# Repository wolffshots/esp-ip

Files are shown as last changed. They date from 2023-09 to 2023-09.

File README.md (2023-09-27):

# ESP32 WiFi Network Interface Bridge

This project is a hardware solution that leverages the power of the ESP32 to bridge local communication interfaces, such as serial and (in the future) I2C, to a WiFi network. It allows devices with traditional communication interfaces to be accessed and controlled over WiFi.

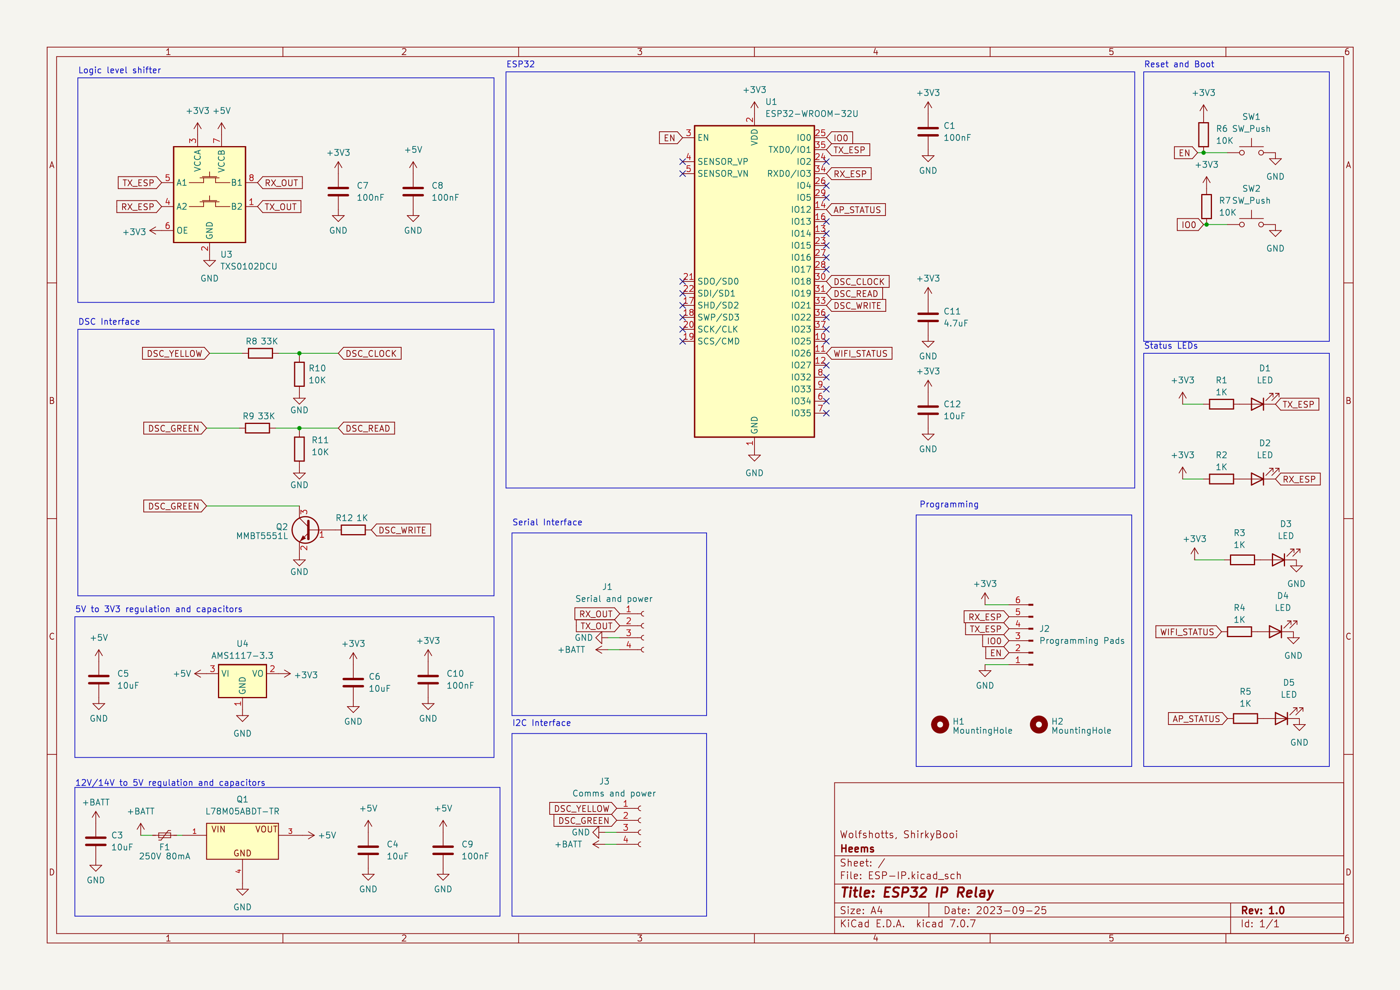
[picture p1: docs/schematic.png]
Schematic diagram


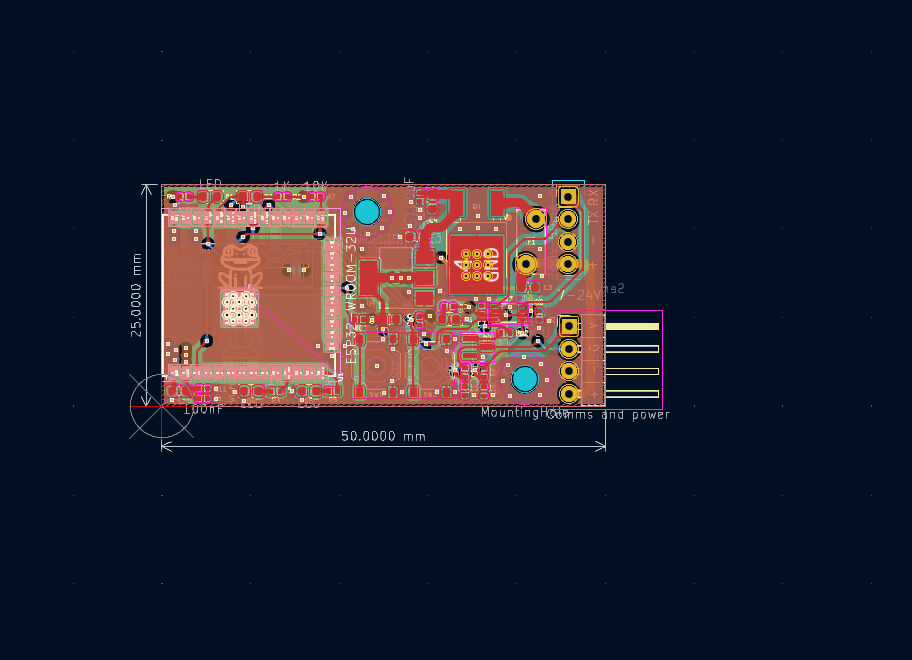
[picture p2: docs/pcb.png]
PCB diagram


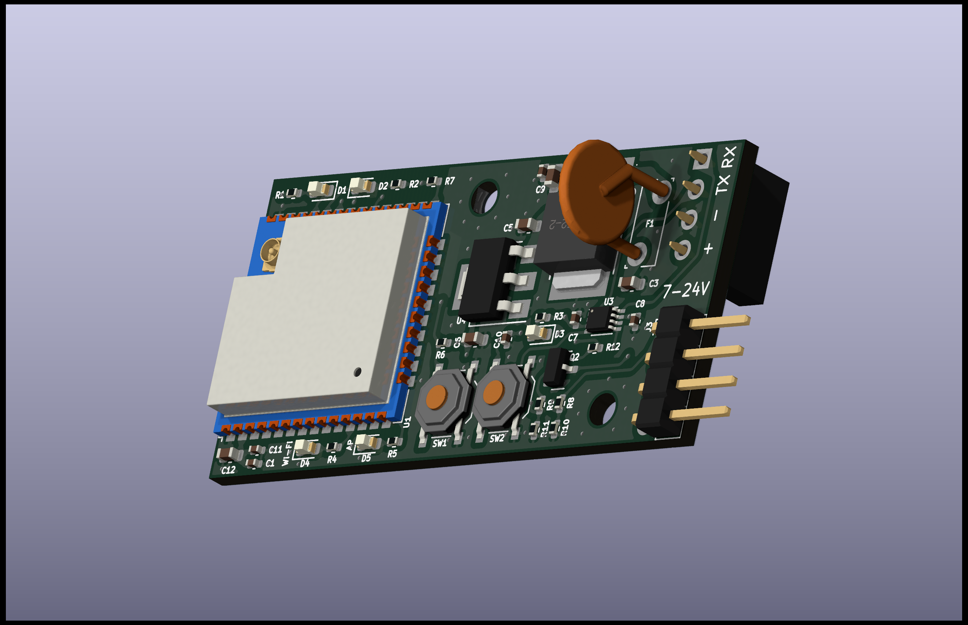
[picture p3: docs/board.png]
Board diagram


## Features

- **Interface Bridging**: Convert and expose devices using:
  - Serial interface (current implementation)
  - I2C interface (planned for future releases)
  
- **WiFi Connectivity**:
  - Connect to an existing WiFi network.
  - Broadcast its own Access Point (AP) for direct connections.

- **Status Indicators**:
  - **Serial Communication**:
    - RX LED: Lights up when the device receives data.
    - TX LED: Lights up when the device transmits data.
  - **WiFi Indicators**:
    - Connection LED: Lights up when the device is connected to an external WiFi.
    - AP LED: Lights up when the device is broadcasting its own Access Point.

## Hardware Design

- Designed in KiCad.
- ESP32-WROOM-32U as the main microcontroller.

## Getting Started

### Prerequisites

- KiCad for viewing and editing the design files.
- A compatible power source for the board.

### Setup

1. **Power the board**: Connect the board to a suitable power source.
2. **Connection**:
    - For Serial: Connect your serial device to the designated serial port.
    - For I2C (Future): Connect your I2C device to the designated I2C connectors.
3. **WiFi**:
    - Connect to an existing WiFi: Set the credentials in the firmware and upload to the ESP32.
    - Use as AP: The board will automatically broadcast its AP if it fails to connect to the saved networks.

### Configuration

Details about how users can configure the firmware for specific WiFi networks, adjust baud rates for serial communication, or other configuration details.

## Future Enhancements

- Integration of the I2C interface.
- Firmware updates over the air.

## Contribute

We welcome contributions! Please read the [CONTRIBUTING.md](./CONTRIBUTING.md) for details on submitting pull requests to us.

## License

This project is licensed under the XYZ License - see the [LICENSE.md](./LICENSE.md) file for details.

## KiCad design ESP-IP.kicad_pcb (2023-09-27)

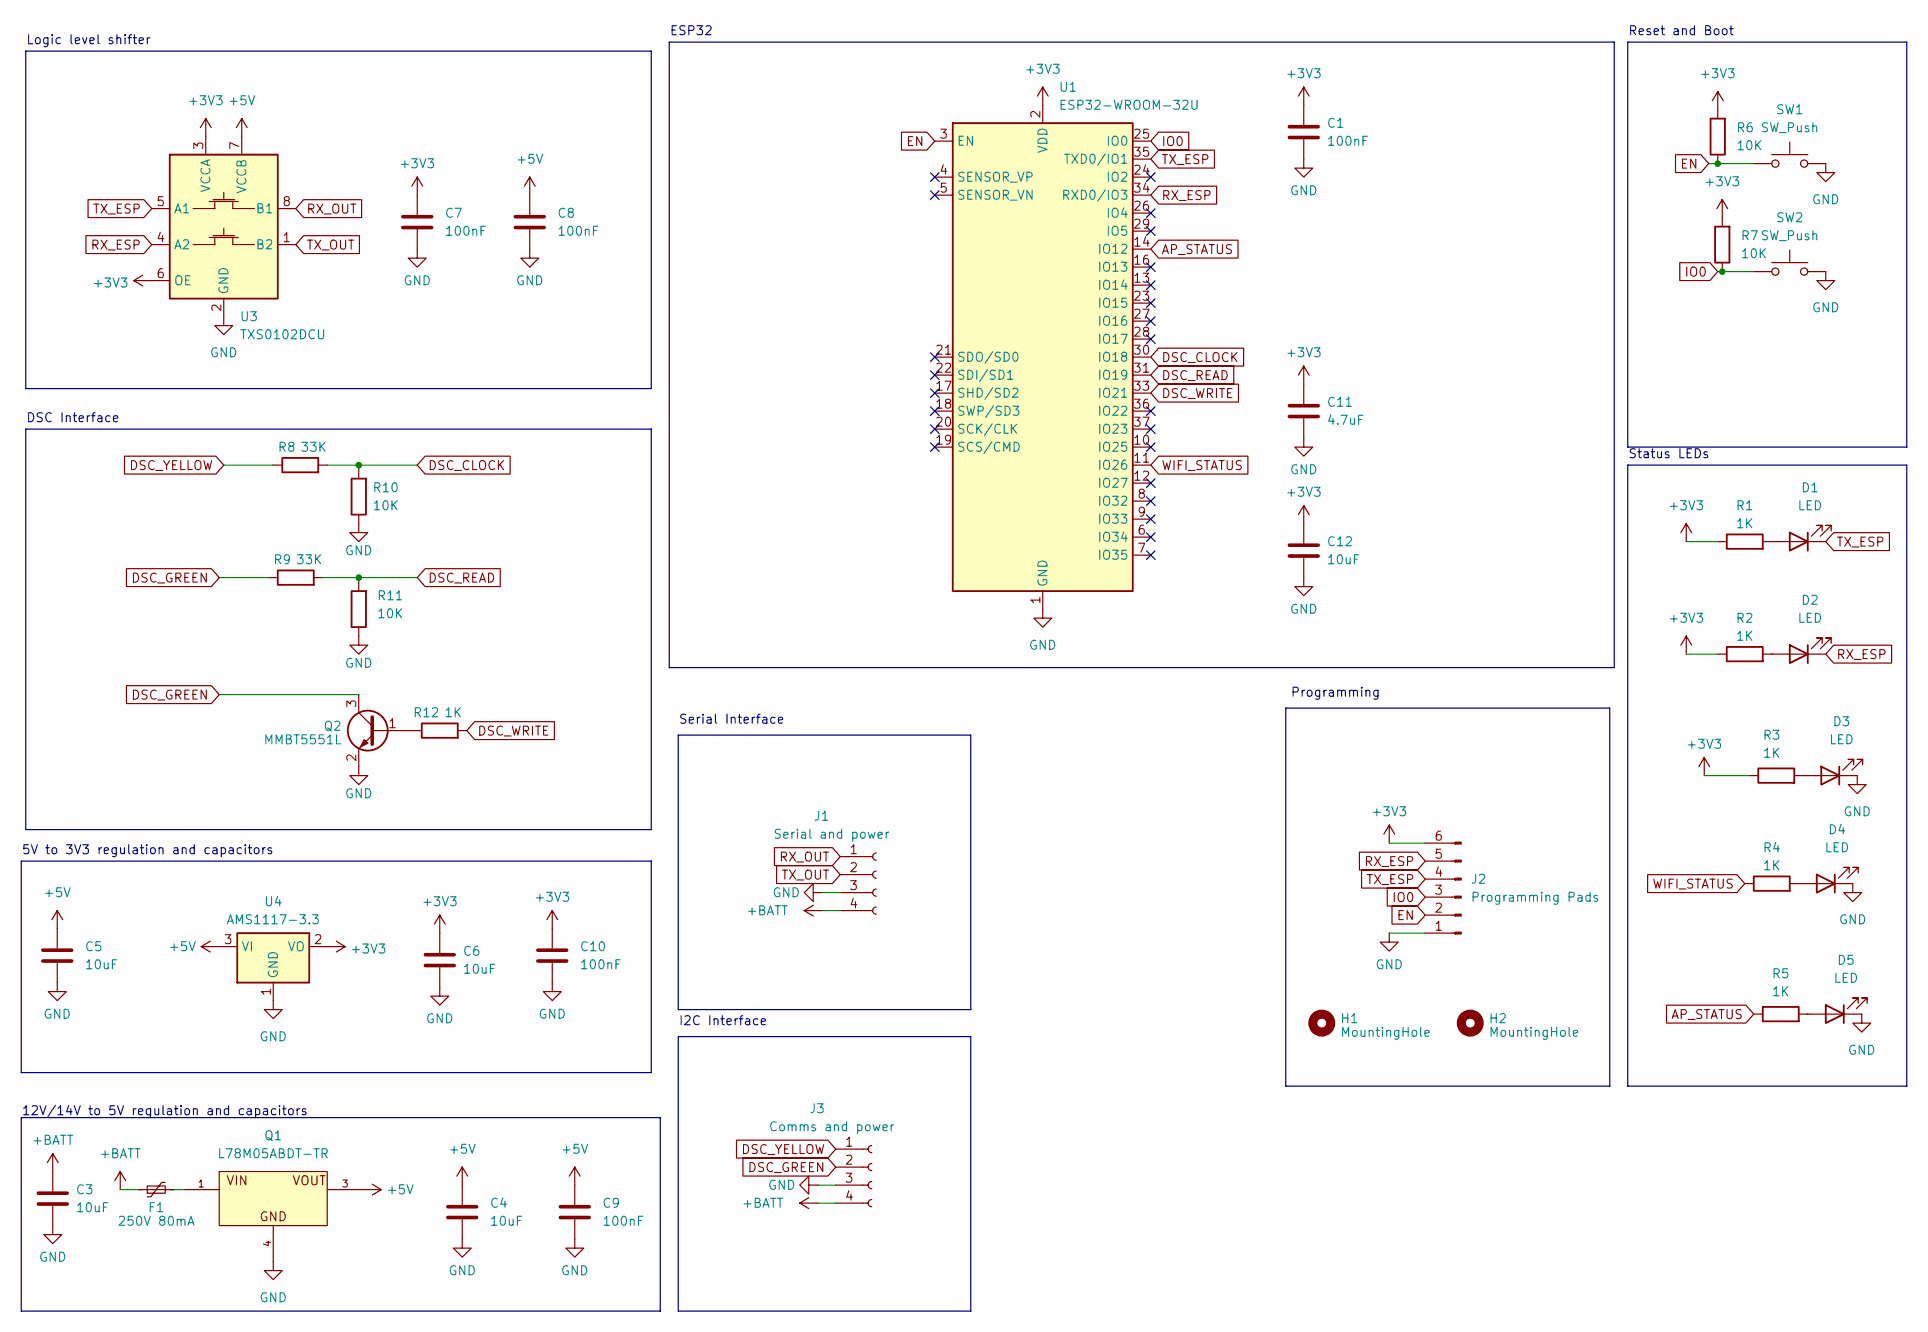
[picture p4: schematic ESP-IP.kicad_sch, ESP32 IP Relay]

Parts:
C1, C7, C8, C9, C10: 100nF; C_0402_1005Metric; LCSC C307331
C3, C4, C5, C6, C12: 10uF; C_0603_1608Metric; LCSC C57112
C11: 4.7uF; C_0402_1005Metric; LCSC C1538
D1, D2: LED; LED_0603_1608Metric; LCSC C2286
D3: LED; LED_0603_1608Metric; LCSC C72038
D4: LED; LED_0603_1608Metric; LCSC C72041
D5: LED; LED_0603_1608Metric; LCSC C72043
F1: 250V 80mA; Fuse_Bourns_MF-RG300; LCSC DNP
H1, H2: MountingHole; MountingHole_2.7mm_M2.5
J1: Serial and power; PinSocket_1x04_P2.54mm_Vertical; LCSC DNP
J2: Programming Pads; PinHeader_1x06_P2.54mm_Vertical_SMD_Pin1Left; LCSC DNP
J3: Comms and power; PinHeader_1x04_P2.54mm_Horizontal; LCSC DNP
Q1: L78M05ABDT-TR; TO-252-2_L6.5-W6.1-P4.58-LS10.0-TL; LCSC C58069
Q2: MMBT5551L; SOT-23; LCSC C2145
R1, R2, R3, R4, R5, R12: 1K; R_0402_1005Metric; LCSC C11702
R6, R7, R10, R11: 10K; R_0402_1005Metric; LCSC C25744
R8, R9: 33K; R_0402_1005Metric; LCSC C25779
SW1, SW2: SW_Push; SW_Push_1P1T_XKB_TS-1187A; LCSC C318884
U1: ESP32-WROOM-32U; ESP32-WROOM-32UE; LCSC DNP
U3: TXS0102DCU; VSSOP-8_2.3x2mm_P0.5mm; LCSC C53434
U4: AMS1117-3.3; SOT-223-3_TabPin2; LCSC C6186

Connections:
+3V3: C1.1, C6.1, C7.1, C10.1, C11.1, C12.1, J2.6, R1.1, R2.1, R3.1, R6.2, R7.2, U1.2 (VDD), U3.3 (VCCA), U3.6 (OE), U4.2 (VO)
+5V: C4.1, C5.1, C8.1, C9.1, Q1.3 (OUT), U3.7 (VCCB), U4.3 (VI)
+BATT: C3.1, F1.1, J1.4, J3.4
AP_STATUS: R5.1, U1.14 (IO12)
DSC_CLOCK: R8.2, R10.2, U1.30 (IO18)
DSC_GREEN: J3.2, Q2.3 (C), R9.1
DSC_READ: R9.2, R11.2, U1.31 (IO19)
DSC_WRITE: R12.2, U1.33 (IO21)
DSC_YELLOW: J3.1, R8.1
EN: J2.2, R6.1, SW1.1, U1.3 (EN)
GND: C1.2, C3.2, C4.2, C5.2, C6.2, C7.2, C8.2, C9.2, C10.2, C11.2, C12.2, D3.1 (K), D4.1 (K), D5.1 (K), J1.3, J2.1, J3.3, Q1.4 (GND), Q2.2 (E), R10.1, R11.1, SW1.2, SW2.2, U1.1 (GND), U1.15 (GND), U1.38 (GND), U1.39 (GND), U3.2 (GND), U4.1 (GND)
IO0: J2.3, R7.1, SW2.1, U1.25 (IO0)
unnamed: D1.2 (A), R1.2
unnamed: D2.2 (A), R2.2
unnamed: D3.2 (A), R3.2
unnamed: D4.2 (A), R4.2
unnamed: D5.2 (A), R5.2
unnamed: F1.2, Q1.1 (IN)
unnamed: Q2.1 (B), R12.1
RX_ESP: D2.1 (K), J2.5, U1.34 (RXD0/IO3), U3.4 (A2)
RX_OUT: J1.1, U3.8 (B1)
TX_ESP: D1.1 (K), J2.4, U1.35 (TXD0/IO1), U3.5 (A1)
TX_OUT: J1.2, U3.1 (B2)
WIFI_STATUS: R4.1, U1.11 (IO26)

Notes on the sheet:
Status LEDs
I2C Interface
Programming
DSC Interface
ESP32
5V to 3V3 regulation and capacitors
12V/14V to 5V regulation and capacitors
Logic level shifter
Serial Interface
Reset and Boot

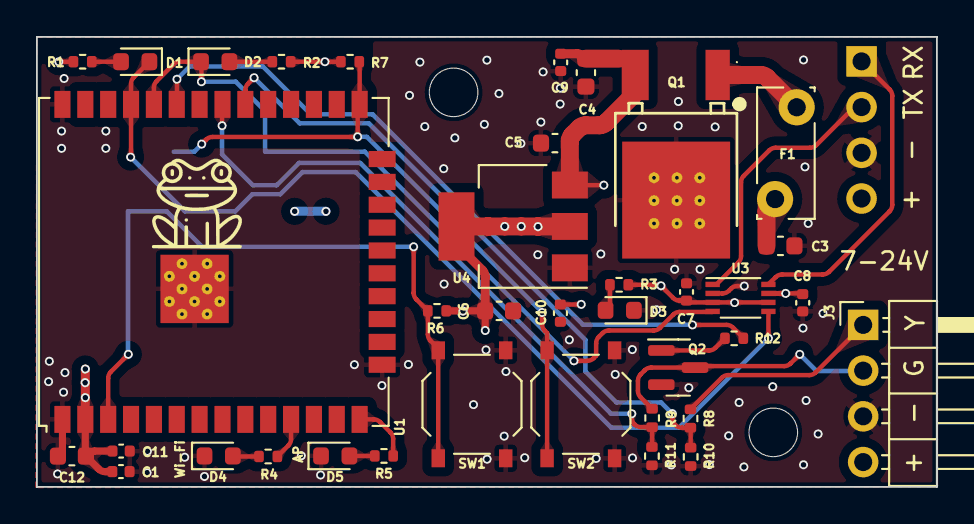
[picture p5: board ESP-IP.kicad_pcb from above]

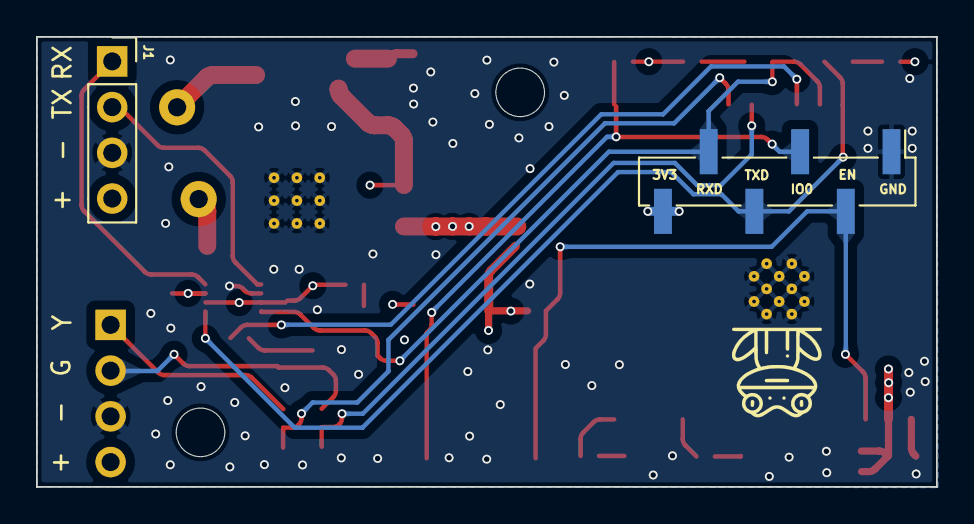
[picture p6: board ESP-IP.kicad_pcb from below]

Board: 4 copper layers, 50.0 x 25.0 mm, 41 parts (2 on the bottom side), 24 nets.

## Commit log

2023-09-25 chore: initial commit
    [ESP-IP.kicad_pcb, ESP-IP.kicad_sch]
2023-09-25 feat: moving around bits and bobs
    [ESP-IP.kicad_pcb, ESP-IP.kicad_sch]
2023-09-25 my suggested board layout, includes schematic fixes, part number allocation and PCB, routing TBD
    [ESP-IP.kicad_pcb, ESP-IP.kicad_sch]
2023-09-25 fixing text mirrored
    [ESP-IP.kicad_pcb]
2023-09-26 chore: switch header back for serial and standardise labels
    [ESP-IP.kicad_pcb, ESP-IP.kicad_sch]
2023-09-26 chore: pull previous pcb in
    [ESP-IP.kicad_pcb]
2023-09-26 chore: switch back to socket for serial
    [ESP-IP.kicad_sch]
2023-09-26 chore: initial routing
    [ESP-IP.kicad_pcb, ESP-IP.kicad_sch]
2023-09-26 chore: swap labels of rx and tx on pin socket
    [ESP-IP.kicad_pcb, ESP-IP.kicad_sch]
2023-09-26 FEAT: ADD FROG
    [ESP-IP.kicad_pcb]
2023-09-26 cleaned up routing and minor PCB changes
    [ESP-IP.kicad_pcb]
2023-09-27 chore: switch rx and tx out
    [ESP-IP.kicad_pcb, ESP-IP.kicad_sch]
2023-09-27 chore: drop some vias and refill
    [ESP-IP.kicad_pcb]
